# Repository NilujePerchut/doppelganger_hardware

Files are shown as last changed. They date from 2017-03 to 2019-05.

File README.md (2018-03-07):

# Doppelganger RevA0
_Niluje (c) 2018_

Joystick interface to Brook PCB and old video game systems.
This is the hardware part of the project,

The project is divided in three parts:
* The main board
* Arcade Adapter: an interface to arcade superguns for the doppelganger
* A BROOK fighting board replacement that allows to plug any USB device on the doppelganger main board

See in each project folder for more details.

## Firmware

See the software project.

## Acknowelegement

The idea is stolen from the MC Cthulu by Toodles.

## Licence

This hardware project is distribuated under the BSD 2-clauses licence.
SEE licence file for more information.

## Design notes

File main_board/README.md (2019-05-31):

# Doppelganger RevB0
_Niluje (c) 2018_

Joystick interface to Brook PCB and old video game systems.
This is the hardware part of the project,

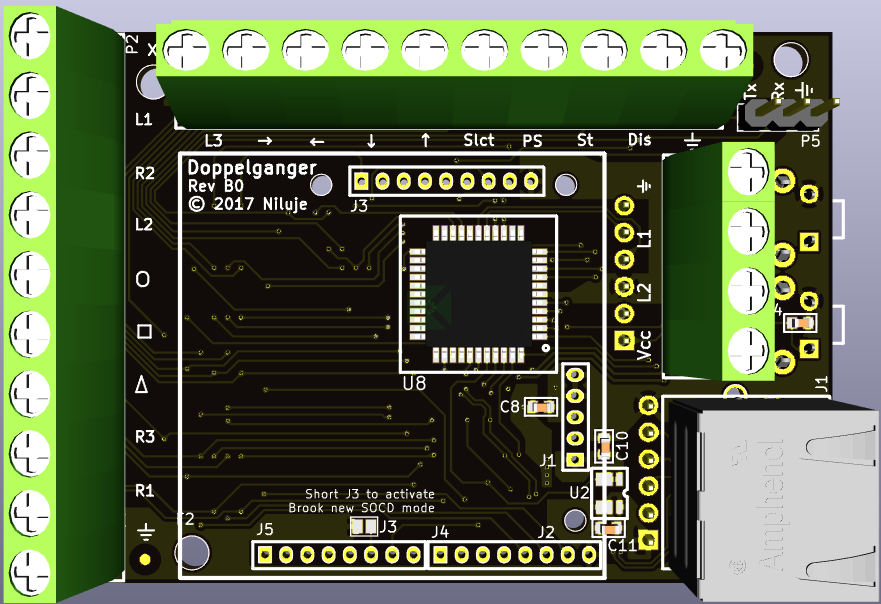
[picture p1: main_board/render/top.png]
Kicad render (top side)

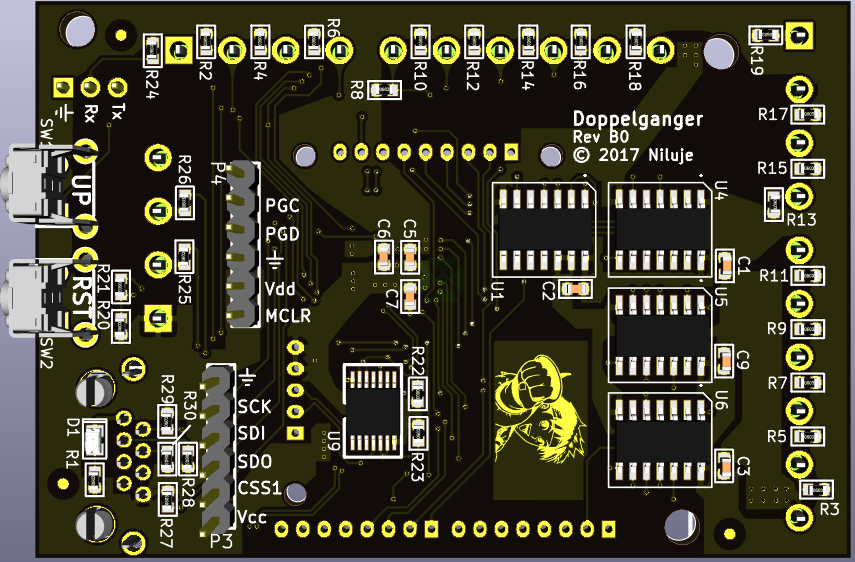
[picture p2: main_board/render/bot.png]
Kicad render (bottom side)


## RJ45 cabling

See the software project.

## Known bugs

Nothing for the moment

## Acknowelegement

The idea is stolen from the MC Cthulu by Toodles.

## Licence

This hardware project is distribuated under the BSD 2-clauses licence.
SEE licence file for more information.

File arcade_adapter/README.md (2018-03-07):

# Arcade Adapter RevB1
_Niluje (c) 2018_

Doppelganger addon board designated to support superguns, and (in the future) controllers with more than 8 wires. ie: Megadrive/Genesys.

This module is compatible with all Doppelganger versions (in case of RevA0, just apply all bug fixes listed in the Doppelganger README.md file).

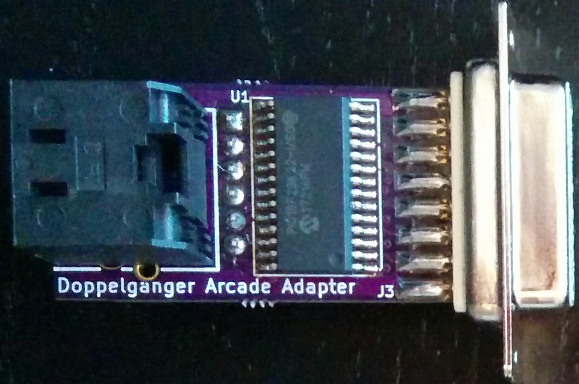
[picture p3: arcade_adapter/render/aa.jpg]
Arcade adapter first batch


## RJ45 cabling

Just use a straight Ethernet cable to connect the Arcade Adapter to the Doppelganger.

## SUBD15 cabling

### Supergun

The default SUBD15 for supergun is given below. But since all pins are connected to the
PIC microcontroller, it is possible to implement any required pinout by modifiing the C code.

Thus, it recommended to check the software for the currently supported pinouts.
For the moment, only one pinout supported is the SmallCab supergun.

| SUBD15 pin | function |
|---|---|
| 1 | Gnd |
| 2 | NC |
| 3 | MK |
| 4 | LK |
| 5 | MP |
| 6 | RIGHT |
| 7 | DOWN |
| 8 | Vcc |
| 9 | HK |
| 10 | COIN |
| 11 | START |
| 12 | HP |
| 13 | LP |
| 14 | LEFT |
| 15 | UP |

* NC does not mean "not connected" to the PIC microcontroller. It is just not connected to the supergun for this configuration.

## Firmware
This board must be used with the Doppelganger arcade adapter available in the Doppelganger software project.

## Known bugs

None for now (hopefuly)

## Licence

This hardware project is distribuated under the BSD 2-clauses licence.
SEE licence file for more information.

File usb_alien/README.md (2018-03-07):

# USB Alien RevA0
_Niluje (c) 2018_

This is an attempt to provide an _any_ USB interface to the Doppelganger board.
This board replaces the BROOK fighting board on the Doppelganger.
You can for example, mount the Doppelganger and the USB alien inside a TE2 and 
plug the TE2 USB to the USB Alien. This will allow the Doppelganger to access 
the TE2 USB.

## Status

Not tested yet.

## Licence

This hardware project is distribuated under the BSD 2-clauses licence.
SEE licence file for more information.

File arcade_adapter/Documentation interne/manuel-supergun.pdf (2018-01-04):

# SUPERGUN SMALLCAB

v1.6

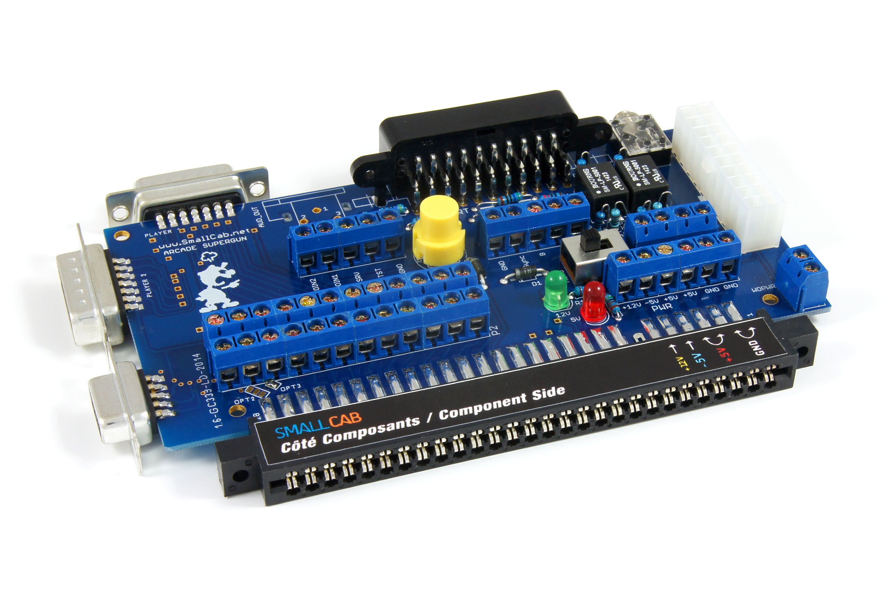
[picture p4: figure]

# MANUEL D'UTILISATION

### WWW.SMALLCAB.NET

# TABLE DES MATIÈRES

1. Présentation | page 3
2. Alimentation du Supergun | page 3
2.1. Alimentation ATX | page 3
2.2. Alimentation Arcade | page 3
2.3. Indicateur de voltage | page 3
3. Gestion du son | page 4
3.1. Switch Mono/Stéréo (SW1) | page 4
3.2. Prise casque (speakers) | page 4
3.3. Borniers audio droit et gauche (Right/Left) | page 4
3.4. Son sur la péritel | page 4
4. Schéma de la carte PCB du supergun | page 5
5. Contrôles | page 6
5.1. Connecteur DB15 | page 6
5.2. Connecteur DB9 | page 6
5.3. Borniers P1/P2 | page 7
5.4. Borniers OPT | page 7
6. Cablage JAMMA mono utilisé | page 8
7. Cablage JAMMA stéréo utilisé | page 9

WWW.SMALLCAB.NET - Page 2

# 1. PRÉSENTATION

Le Supergun SmallCab est une carte électronique qui permet d'utiliser une carte (PCB) JAMMA sur un téléviseur équipé d'une prise péritel. Il est compatible avec les cartes (PCB) JAMMA utilisant jusqu'à six boutons sur le conecteur JAMMA (Pandora Box par exemple). Vous pouvez utiliser un stick Neo Geo (port DB15) ou des joysticks et boutons d'arcade (bornier P1Bis et P2Bis).

Un switch permet de passer de mono à stéréo pour les PCB gérant la stéréo. Un bouton insert coin placer au centre du Supergun permet de passer les crédits directement à la carte (PCB) JAMMA.

La sortie péritel permet de diffuser l'image (seule la sortie RGB est supportée, pas la composite ni la S-Vidéo) ainsi que le son (seulement sur la version deluxe) sur votre téléviseur.

Afin d'éviter tout problème, veuillez éteindre le téléviseur avant de changer de carte (PCB) JAMMA.

# 2. ALIMENTATION DU SUPERGUN

# 2.1. Alimentation ATX

Vous pouvez utiliser une alimentation ATX de type Bronze Plus 80 à partie de 350W (connecteur 20 ou 24 points acceptés).

Les alimentation ATX présentent l'avantage d'être auto régulée et fonctionnent parfaitement avec de petites carte JAMMA comme les PandoraBox ou les Slot MVS (avec un seul port cartouche). Pour des cartes JAMMA plus importantes comme un slot MVS disposant de quatre ports ce type d'alimentation ne sera pas suffisante.

A noter que le -5V disponible dans les premières versions du standard ATX n'est actuellement plus disponible. L'absence de ce -5V peux entrainer un incompatibilité avec quelques très rare jeux.

# 2.2. Alimentation Arcade

Les alimentations Arcade ne sont pas auto régulés et nécessitent d'être réglée pour chaque jeu avec un voltmètre ce qui leur usage plus contraignant.

Pour connecter une alimentation Arcade sur nos Superguns il convient de relier :

- Le +5V de l'alimentation au bornier +5V du Supergun
- Le -5V de l'alimentation au bornier -5V du Supergun
- Le +12V de l'alimentation au bornier +12V du Supergun
- Le GND de l'alimentation au bornier GND du Supergun

# 2.3. Indicateur de voltage

La LED rouge indique la présence du 5V sur le Supergun.
Nb: Cette LED est une information de présence du +5V. Le Supergun peut être en survoltage ou en sous-voltage

La LED verte indique la présence du 12V sur le Supergun.

# 3. GESTION DU SON

# 3.1. Switch Mono/Stéréo (SW1)

Le Supergun dispose d'un switch Mono/Stéréo que vous devez positionner en fonction de la PCB que vou sutilisez. Ce switch doit être positionné sur Mono pour la plupart des cartes (PCB) JAMMA.
Le site Arcade Museum (http://www.arcade-museum.com/) référence un grand nombre de PCB et vous permettra de déterminer si votre PCB est de type mono ou stéréo.

Lorsque le switch (SW1) est positionné sur Mono, le signal audio est alors envoyé simultanément sur les hauts parleurs de droite et de gauche.

Pour les PCB disposant du mode stéréo sur le port JAMMA il convient de positionner le switch sur Stéréo. Les deux canaux seront alors répartit sur les hauts parleurs de droite et de gauche.

# 3.2. Prise casque (speakers)

La sortie casque permet de récupérer le son avec un casque ou des enceintes non amplifiés.
Dès que cette sortie est utilisée, le son est coupé et n'est plus disponible au niveau des borniers et de la prise péritel (version deluxe).

# 3.3. Borniers audio droit et gauche (Right/Left)

Le son disponible sur les borniers est amplifié et provient directement de votre PCB JAMMA.Le volume se règle directement sur votre PCB. Vous pouvez connecter des hauts parleurs 8Ohms directement sur les borniers R+,R- et L+,L-

# 3.4. Son sur la péritel

Sur la version Deluxe le son stéréo est disponible sur la prise péritel. Le son est atténué par deux transformateurs bourns afin de ne pas abimer l'amplificateur audio qui est intégré à votre téléviseur.

# 4. SCHÉMA DE LA CARTE PCB DU SUPERGUN

J2

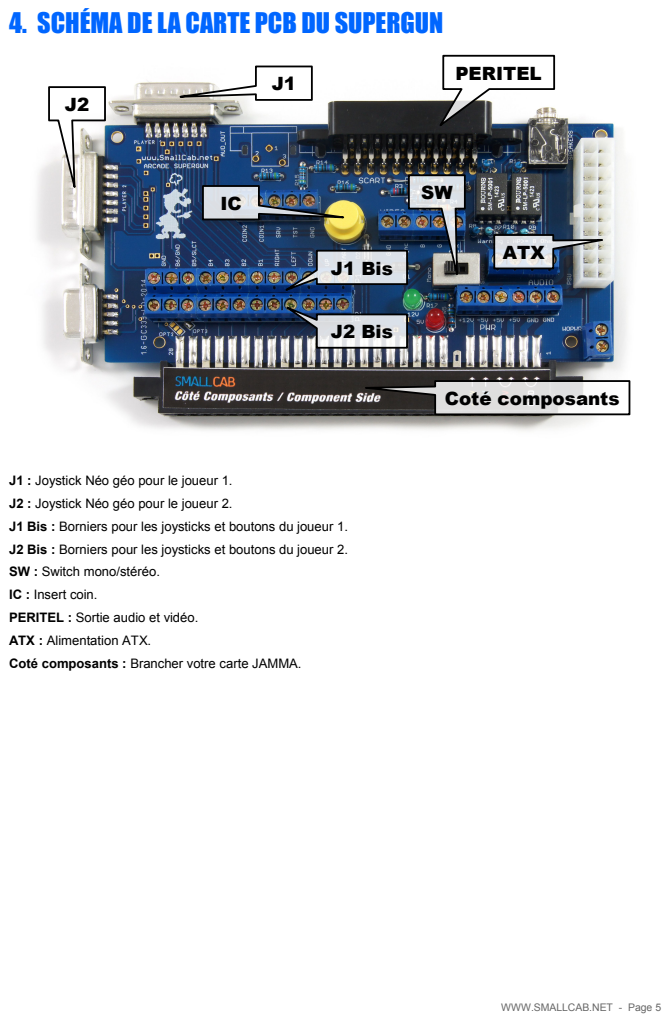
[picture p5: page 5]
J1 Bis; J2 Bis; PERITEL; ATX; Coté composants

J1 : Joystick Néo géo pour le joueur 1.
J2 : Joystick Néo géo pour le joueur 2.
J1 Bis : Borniers pour les joysticks et boutons du joueur 1.
J2 Bis : Borniers pour les joysticks et boutons du joueur 2.
SW : Switch mono/stéréo.
IC : Insert coin.
PERITEL : Sortie audio et vidéo.
ATX : Alimentation ATX.
Coté composants : Brancher votre carte JAMMA.

# 5. CONTRÔLES

# 5.1. Connecteur DB15

Le Supergun dispose de deux ports manette DB15 au standard Neo Geo.
Toutes les manettes Neo Geo sont donc compatible avec le Supergun
Cas des manettes "Cacahuète'. Pour fonctionner, ces manettes ont besoins d'être alimenté en +5V, celà est possible en soudant les pastilles P1_PWR (manette du joueur 1) et P2_PWR (manette du joueur 2).
Afin de répondre à toutes les attentes des joueurs, nouis avons fait évoluer le standard DB15 de la Neo Geo. Cela nous permet ainsi de gérer un 6ème bouton et d'intégrer un bouton "Insert Coin" bien pratique pour ajouter des crédits en pleine partie.

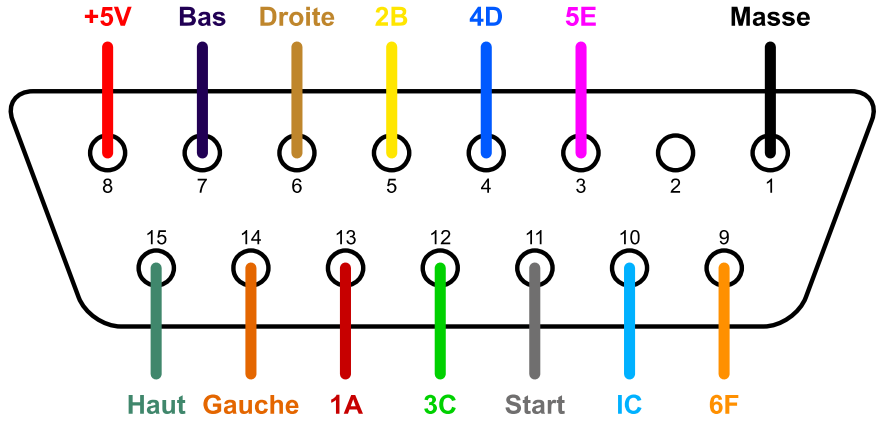
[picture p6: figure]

# 5.2. Connecteur DB9

Le port DB9 sert de Kick harness universel au Supergun SmallCab.
Le kick harness désigne un câblage "hors standard JAMMA" spécifique à certaine PCB comme les PCB CPS1/2 et 3.
Ce connecteur additionnel permet de câbler les boutons 5 et 6 (dans certains cas le bouton 4) non disponible dans le standard JAMMA.
Les Kick harness CPS 1/2 et 3 sont disponibles en option.

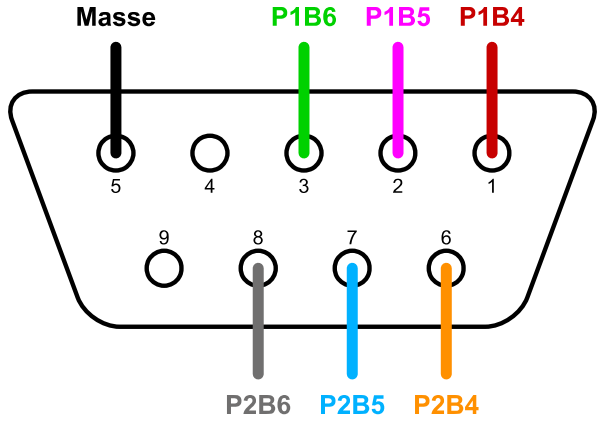
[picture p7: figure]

# 5.3. Borniers P1/P2

Ces borniers permettent de câbler directement le joystick et les 6 boutons du joueur 1 (borniers P1) ainsi que le joystick et les boutons du joueur 2 (borniers P2)

# 5.4. Borniers OPT

Les borniers optionnels permettent de connecter les boutons suivants:

- Test (TST) pour les PCB qui le gère, ajout d'un crédit au jeu sans incrémenter le compteur de crédit.
- Service (SRV) Permet de rentrer dans le paramétrage de la carte pour les PCB qui le gère.
- Insert coin 1 (COIN1) Ajout d'un crédit au jeu (plus incrémentation du compteur de crédit)
- Insert coin 2 (COIN2) Ajout d'un crédit au joueur 2 (plus incrémentation du compteur de crédit). Très peu de carte gère deux monnayeurs pour une PCB.

# 6. CABLAGE JAMMA MONO UTILISÉ

COTÉ COMPOSANT | COTÉ SOUDURE
GND (Masse) | 1 | A | GND (Masse)
GND (Masse) | 2 | B | GND (Masse)
+5V | 3 | C | +5V
+5V | 4 | D | +5V
- 5V | 5 | E | - 5V
+12V | 6 | F | +12V
| 7 H
Non utilisé | 8 | J | Non utilisé
Non utilisé | 9 | K | Non utilisé
Haut parleur + | 10 | L | Haut parleur -
Non utilisé | 11 | M | Setup -TST (Paramétrage)
Vidéo - Rouge | 12 | N | Vidéo - Vert
Vidéo - Bleu | 13 | P | Vidéo - Synchro
Vidéo - GND (Masse) | 14 | R | Service (Srv)
Setup -TST (Paramétrage) | 15 | S | Non utilisé
Coin J1 (Crédit) | 16 | T | Coin J2 (Crédit)/Test NeoGeo 64
J1 - Start | 17 | U | J2 - Start
J1 - Haut | 18 | V | J2 - Haut
J1 - Bas | 19 | W | J2 - Bas
J1 - Gauche | 20 | X | J2 - Gauche
J1 - Droite | 21 | Y | J2 - Droite
J1 - Bouton 1 | 22 | Z | J2 - Bouton 1
J1 - Bouton 2 | 23 | a | J2 - Bouton 2
J1 - Bouton 3 | 24 | b | J2 - Bouton 3
J1 - Bouton 4 | 25 | c | J2 - Bouton 4
J1 - Bouton 5 | 26 | d | J2 - Bouton 5
J1 - Bouton 6 (bornier) | 27 | e | J2 - Bouton 6 (bornier)
GND (Masse) | 28 | f | GND (Masse)

# 7. CABLAGE JAMMA STÉRÉO UTILISÉ

COTÉ COMPOSANT | COTÉ SOUDURE
GND (Masse) | 1 | A | GND (Masse)
GND (Masse) | 2 | B | GND (Masse)
+5V | 3 | C | +5V
+5V | 4 | D | +5V
- 5V | 5 | E | - 5V
+12V | 6 | F | +12V
| 7 H
Non utilisé | 8 | J | Non utilisé
Non utilisé | 9 | K | Non utilisé
Haut parleur R (droit) | 10 | L | Haut parleur L (gauche)
Non utilisé | 11 | M | Setup -TST (Paramétrage)
Vidéo - Rouge | 12 | N | Vidéo - Vert
Vidéo - Bleu | 13 | P | Vidéo - Synchro
Vidéo - GND (Masse) | 14 | R | Service (Srv)
Setup -TST (Paramétrage) | 15 | S | Non utilisé
Coin J1 (Crédit) | 16 | T | Coin J2 (Crédit)/Test NeoGeo 64
J1 - Start | 17 | U | J2 - Start
J1 - Haut | 18 | V | J2 - Haut
J1 - Bas | 19 | W | J2 - Bas
J1 - Gauche | 20 | X | J2 - Gauche
J1 - Droite | 21 | Y | J2 - Droite
J1 - Bouton 1 | 22 | Z | J2 - Bouton 1
J1 - Bouton 2 | 23 | a | J2 - Bouton 2
J1 - Bouton 3 | 24 | b | J2 - Bouton 3
J1 - Bouton 4 | 25 | c | J2 - Bouton 4
J1 - Bouton 5 | 26 | d | J2 - Bouton 5
J1 - Bouton 6 (bornier) | 27 | e | J2 - Bouton 6 (bornier)
GND (Masse) | 28 | f | GND (Masse)

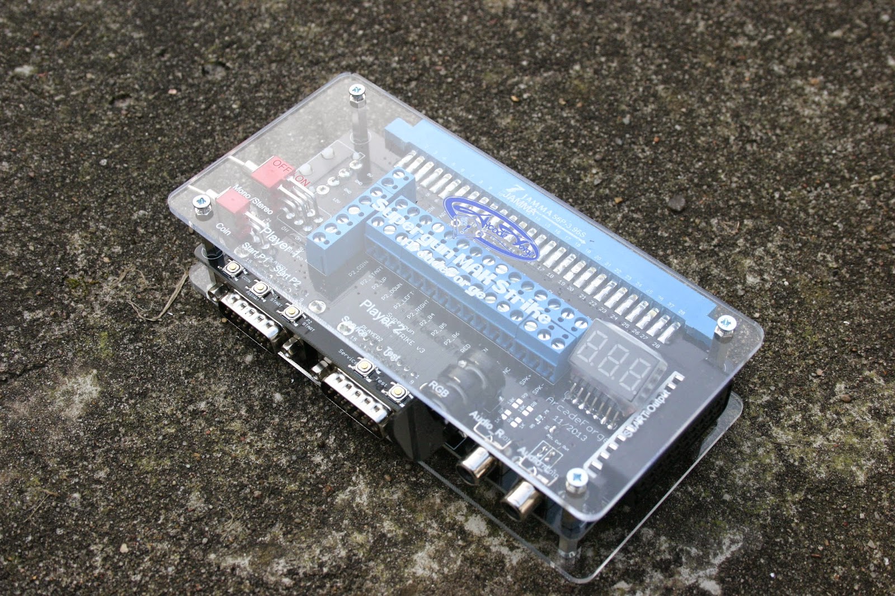
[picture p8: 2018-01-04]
arcade_adapter/Documentation interne/Supergun MAK Strike - ArcadeForge_fichiers/MAK_002.JPG

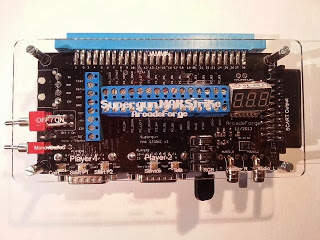
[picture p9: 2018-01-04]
arcade_adapter/Documentation interne/Supergun MAK Strike - ArcadeForge_fichiers/MAK_Strike_v3_04.jpg

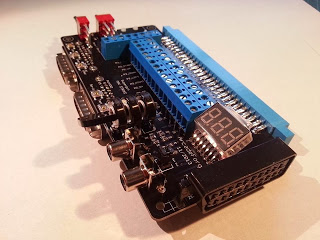
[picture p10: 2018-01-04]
arcade_adapter/Documentation interne/Supergun MAK Strike - ArcadeForge_fichiers/MAK_Strike_v3_00.jpg

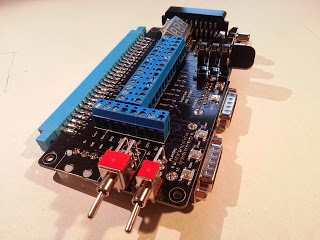
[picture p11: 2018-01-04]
arcade_adapter/Documentation interne/Supergun MAK Strike - ArcadeForge_fichiers/MAK_Strike_v3_01.jpg

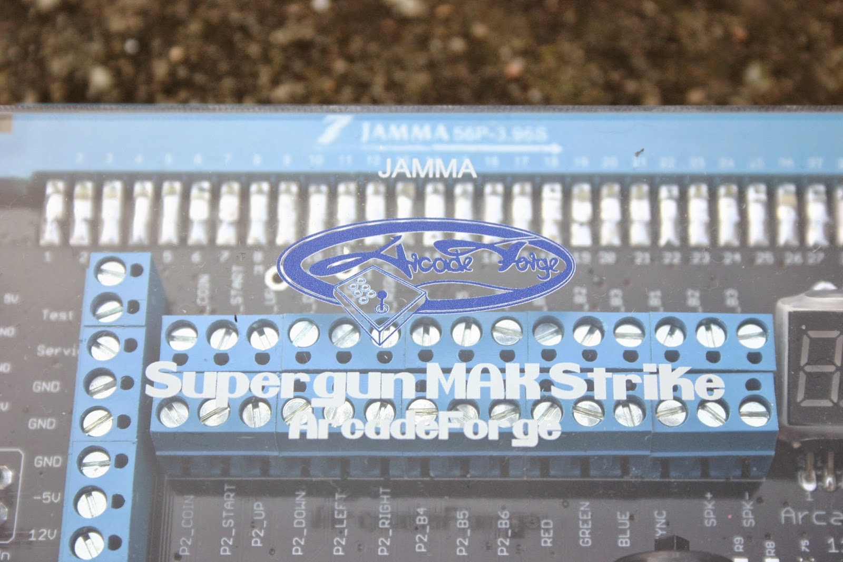
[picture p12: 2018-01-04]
arcade_adapter/Documentation interne/Supergun MAK Strike - ArcadeForge_fichiers/_MAK_009.JPG

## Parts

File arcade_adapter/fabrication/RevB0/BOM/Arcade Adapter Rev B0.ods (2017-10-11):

Arcade adapter Rev B0
Designator | Quantity | Manufacturer | Reference | SMD pins | TH pins | Total SMD | Total TH | Package | Element 14
C3,C2,C1 | 3 | Any | 100nF 10V X7R | 2 | 0 | 6 | 0 | SMD 0603 | 2522597
R4,R2 | 2 | Any | 330R 5 % | 2 | 0 | 4 | 0 | SMD 0603 | 2447339
R3 | 1 | Any | 100R 5 % | 2 | 0 | 2 | 0 | SMD 0603 | 2447227
R1 | 1 | Any | 10K 5 % | 2 | 0 | 2 | 0 | SMD 0603 | 2074170
D2,D1 | 2 | Dialight | LED verte 5988170107F | 2 | 0 | 4 | 0 | SMD 0805 | 1465996
J3 | 1 | Multicomp | SUBD15 à souder | 15 | 0 | 15 | 0 | SMD DB15F_CI | 1084693
J1 | 1 | Amphénol | RJ45 | 0 | 8 | 0 | 8 | TH | 1849917
J2 | 1 | NA | 6 pins 2.54mm header | 0 | 6 | 0 | 6 | TH | NA
U1 | 1 | Microchip | PIC18F23K22-I/SO | 28 | 0 | 28 | 0 | SMD SOIC-28 | 2315850

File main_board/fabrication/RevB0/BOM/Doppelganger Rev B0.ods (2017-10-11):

Doppelganger Rev B0
Designator | Quantity | Manufacturer | Reference | SMD pins | TH pins | Total SMD | Total TH | Package | Element 14
C2,C3,C4,C5,C6,C8,C9,C1,C10 | 9 | Any | 100nF 10V X7R | 2 | 0 | 18 | 0 | SMD 0603 | 2522597
C7 | 1 | Any | 330nF 10V X7R | 2 | 0 | 2 | 0 | SMD 0603 | 2524838
C11 | 1 | Any | 4.7µF 10V X5R | 2 | 0 | 2 | 0 | SMD 0603 | 2320818
R9,R28,R24,R23,R22,R20,R19,R18,R17,R16,R15,R13,R12,R11,R10,R8,R7,R6,R5,R4,R3,R2,R14 | 23 | Any | 10K 5 % | 2 | 0 | 46 | 0 | SMD 0603 | 2074170
R29,R27 | 2 | Any | 3K5 1 % | 2 | 0 | 4 | 0 | SMD 0603 | 2447361
R26,R1,R25 | 3 | Any | 330R 5 % | 2 | 0 | 6 | 0 | SMD 0603 | 2447339
R21 | 1 | Any | 100R 5 % | 2 | 0 | 2 | 0 | SMD 0603 | 2447227
R30 | 1 | Any | 4K7 5 % | 2 | 0 | 2 | 0 | SMD 0603 | 2694880
P6 | 1 | Any | Bornier 5mm pitch 4 pins | 0 | 4 | 0 | 4 | BORNIER4 | 3089058
P2,P1 | 2 | Any | Boernier 5mm pitch 10 pins | 0 | 10 | 0 | 20 | BORNIER_10 | 1793681
SW2,SW1 | 2 | NA | Push button | 0 | 4 | 0 | 8 | TH | NA
P5 | 1 | NA | 3 pins 2.54mm header | 0 | 3 | 0 | 3 | TH | NA
U1 | 1 | Texas instruments | 74HC32M96 | 14 | 0 | 14 | 0 | SMD SOIC-14 | 2458515
U4,U5,U6 | 3 | Texas Instruments | 74LVC07ADR | 14 | 0 | 42 | 0 | SMD SOIC-14 | 9592660
U8 | 1 | Microchip | 18F45K50-I/PT | 44 | 0 | 44 | 0 | SMD TQFP44 | 2305837
U9 | 1 | Nxperia | 74HC4066D-Q100,118 | 14 | 0 | 14 | 0 | SMD TSSOP14 | 2445241
J1 | 1 | Amphenol | RJ45 | 0 | 10 | 0 | 10 | TH | 1849917
P3,P4 | 2 | NA | 6 pins 2.54mm header | 0 | 6 | 0 | 12 | TH | NA
D1 | 1 | Dialight | LED verte 5988170107F | 2 | 0 | 2 | 0 | SMD 0805 | 1465996
J2 | 1 | NA | 2mm headers | 0 |  | 0 | 0 | TH | NA
U2 | 1 | Vishay | SIP32510DT-T1-GE3 | 6 | 0 | 6 | 0 | SMD TSOT-23-6 | 2361514
 |  | Total
Total SMD pins | 204
Total TH pins | 57

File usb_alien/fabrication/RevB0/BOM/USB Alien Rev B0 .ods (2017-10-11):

USB Alien RevB0
Designator | Quantity | Manufacturer | Reference | SMD pins | TH pins | Total SMD | Total TH | Package | Element 14 | Designation | Supplier and ref
P2,P1 | 2 | Multicomp | 4 pin 3.81mm connector | 0 | 4 | 0 | 8 | TH | 2007987
C2,C1 | 2 | Any | 100nF 10V X7R | 2 | 0 | 4 | 0 | SMD 0603 | 2522597
U2,U1 | 2 | Texas Instruments | 4 NAND2 gate | 14 | 0 | 28 | 0 | SMD SOIC-14 | 9590870
J2 | 1 | NA | 2.54 mm pitch 2x12 header | 0 | 24 | 0 | 24 | HE-10_2x12_2.54 | NA
P4,P3 | 2 | Multicomp | 10 pin 3.81mm connector | 0 | 10 | 0 | 20 | TH | 2007993 | BORNIER_10
D1 | 1 | Dialight | LED verte 5988170107F | 2 | 0 | 2 | 0 | SMD 0805 | 1465996
J1 | 1 | NA | Brook adapter | 0 | 30 | 0 | 30 | TH | NA
R1 | 1 | Any | 330R 5 % | 2 | 0 | 2 | 0 | SMD 0603 | 2447339

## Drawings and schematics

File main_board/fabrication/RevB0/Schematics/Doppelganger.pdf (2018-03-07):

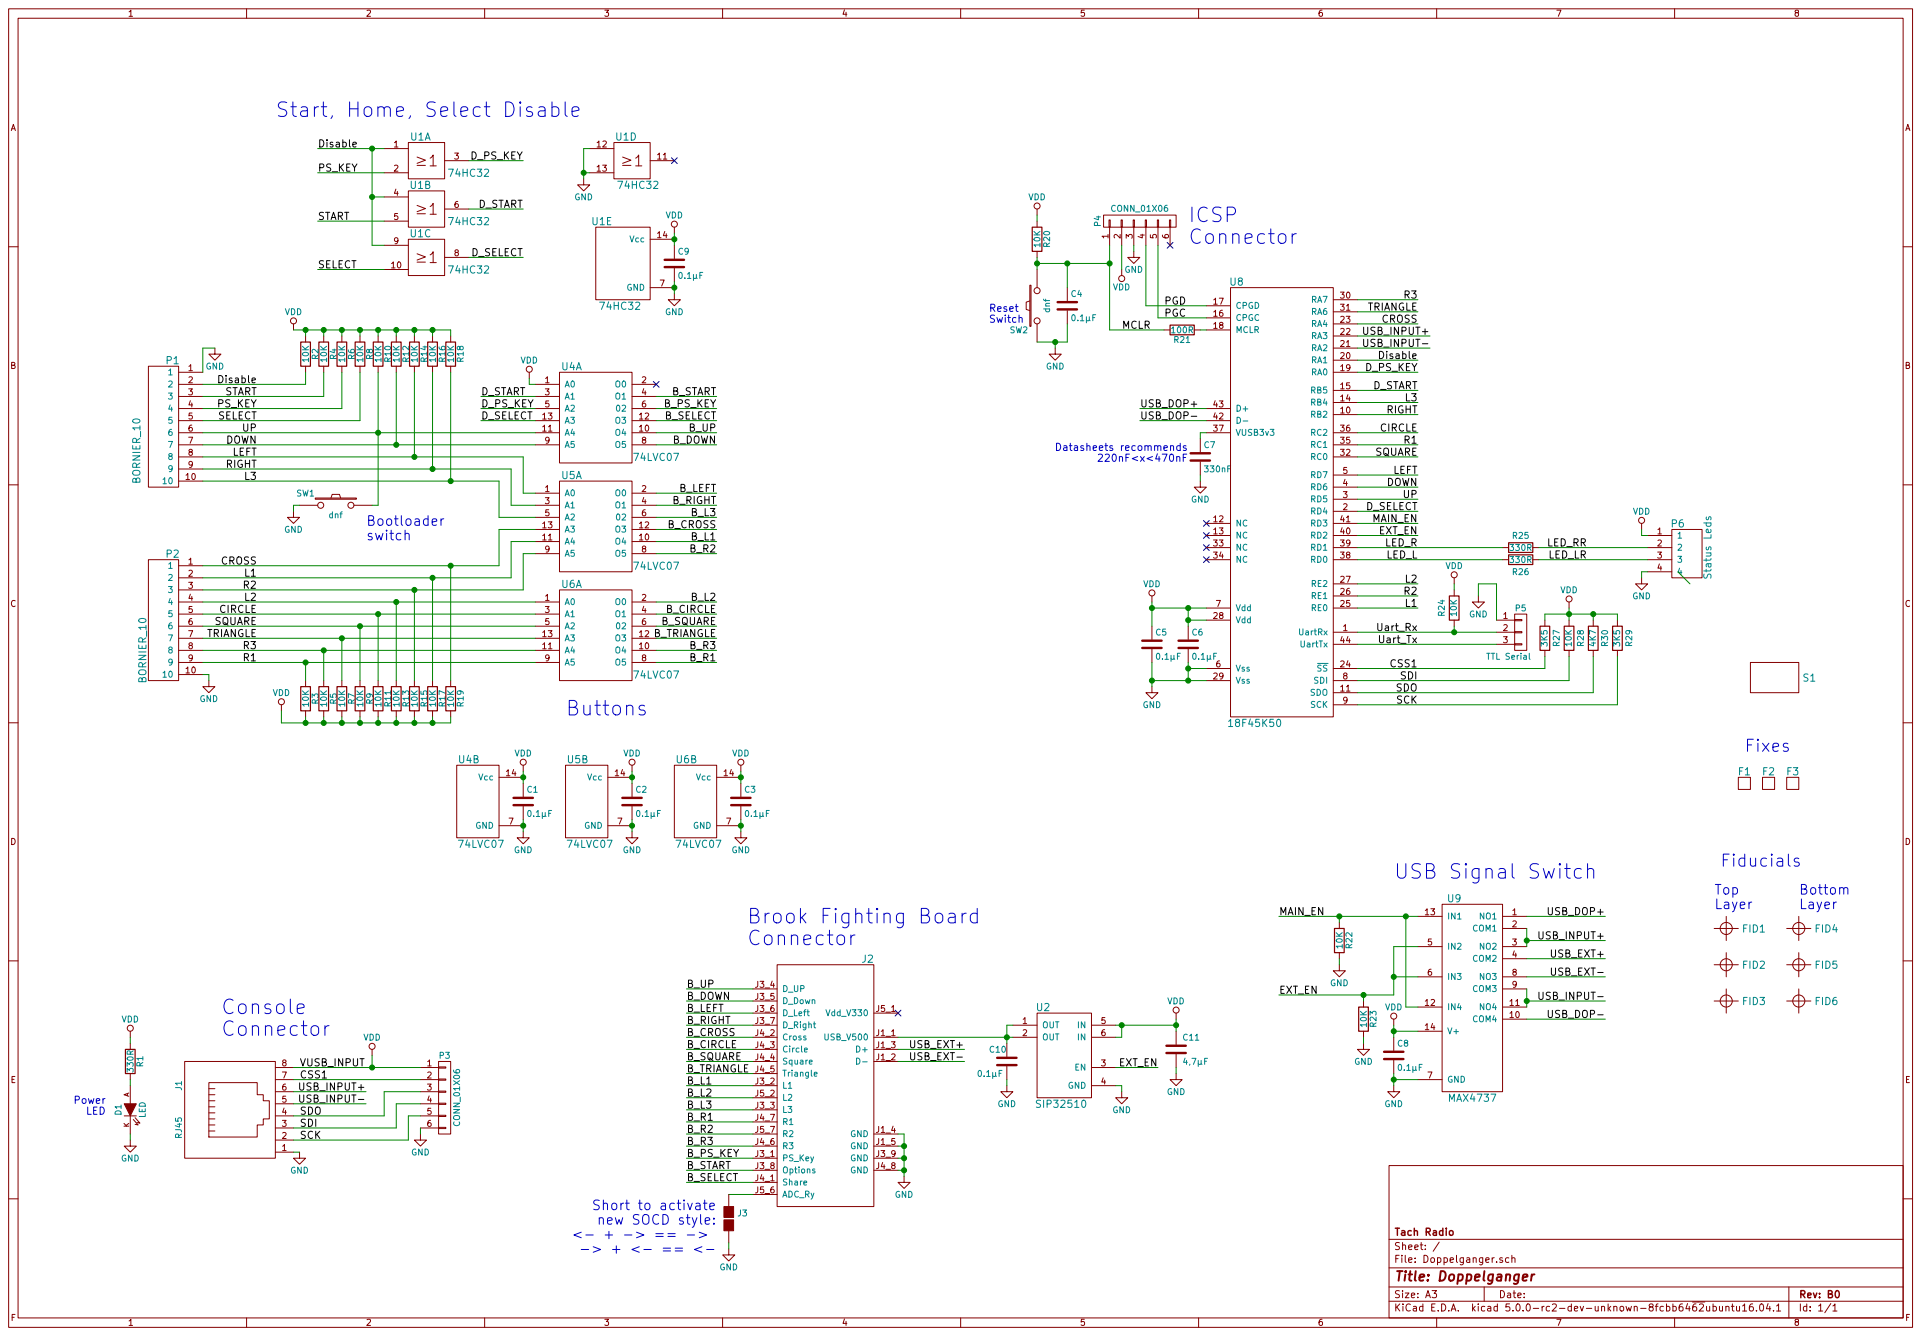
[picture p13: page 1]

Start, Home, Select Disable

LED_L | LED_LR | 3

4 | 02 O4 O3 O0 O1 | 8 A5 9 U6A 10 A4 11 12 A3 13 2 A1 3 4 A2 5

CIRCLE 5 | | | A0 1 | 6 O5 B_CIRCLE

6 | | | | B_SQUARE
7 | | | | | | B_TRIANGLE
8 | | | | | B_R3

J3 GND Short to activate

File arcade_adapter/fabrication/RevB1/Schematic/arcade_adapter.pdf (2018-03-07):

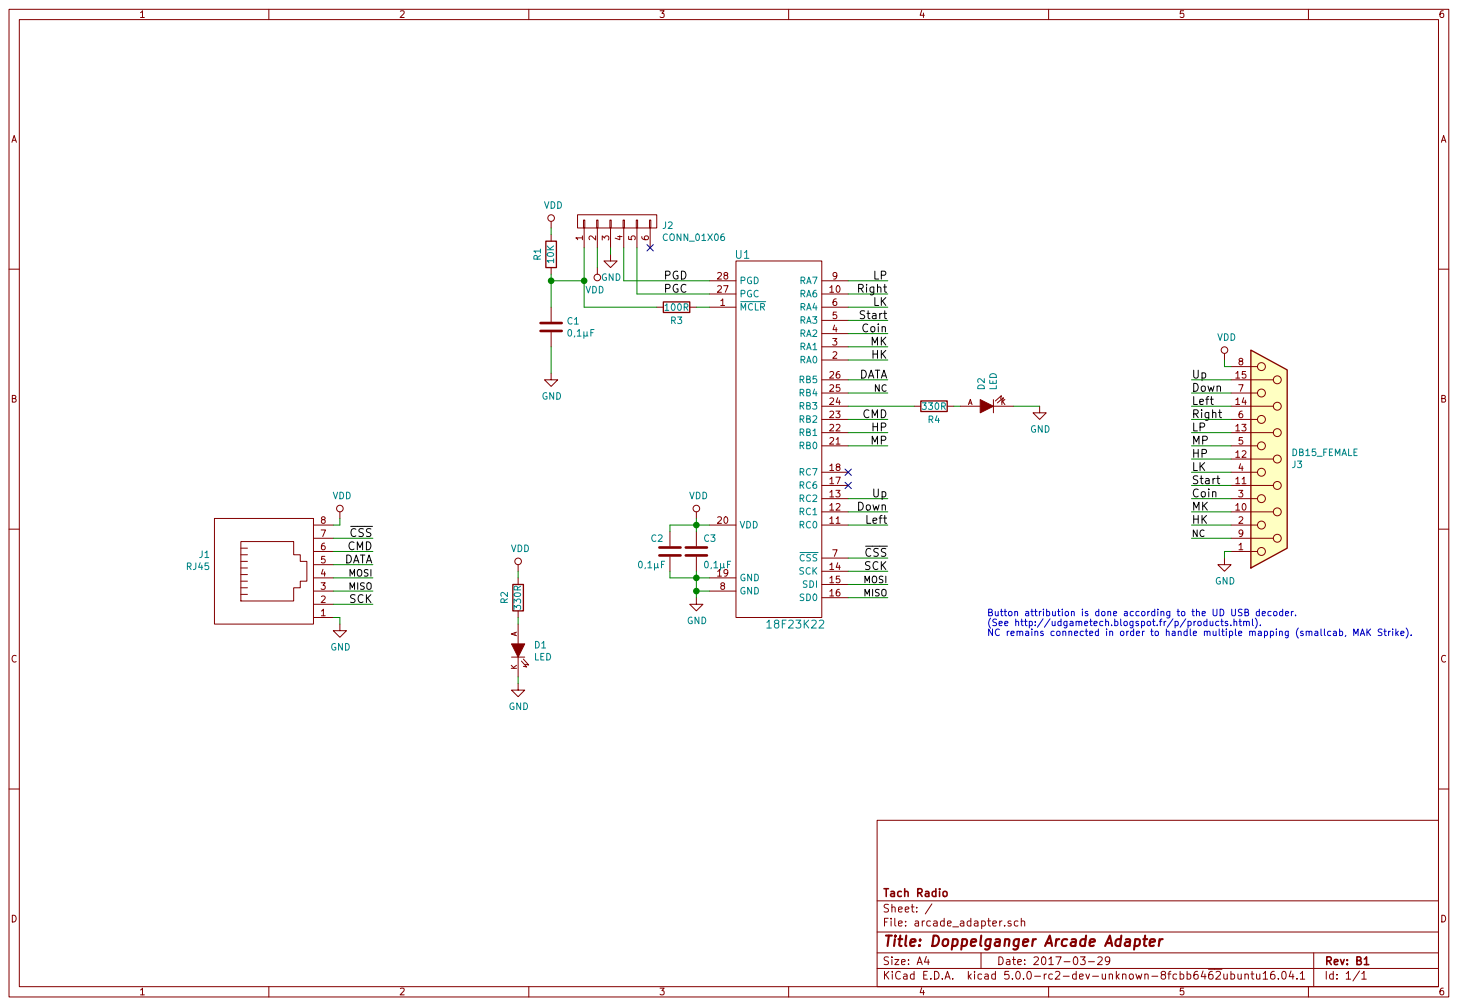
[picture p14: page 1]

LP Right Left DownUp
LKMP
Start MK
Coin

Button attribution is done according to the UD USB decoder.
(See http://udgametech.blogspot.fr/p/products.html).
NC remains connected in order to handle multiple mapping (smallcab, MAK Strike).

Id: 1/1 Title: Doppelganger Arcade Adapter

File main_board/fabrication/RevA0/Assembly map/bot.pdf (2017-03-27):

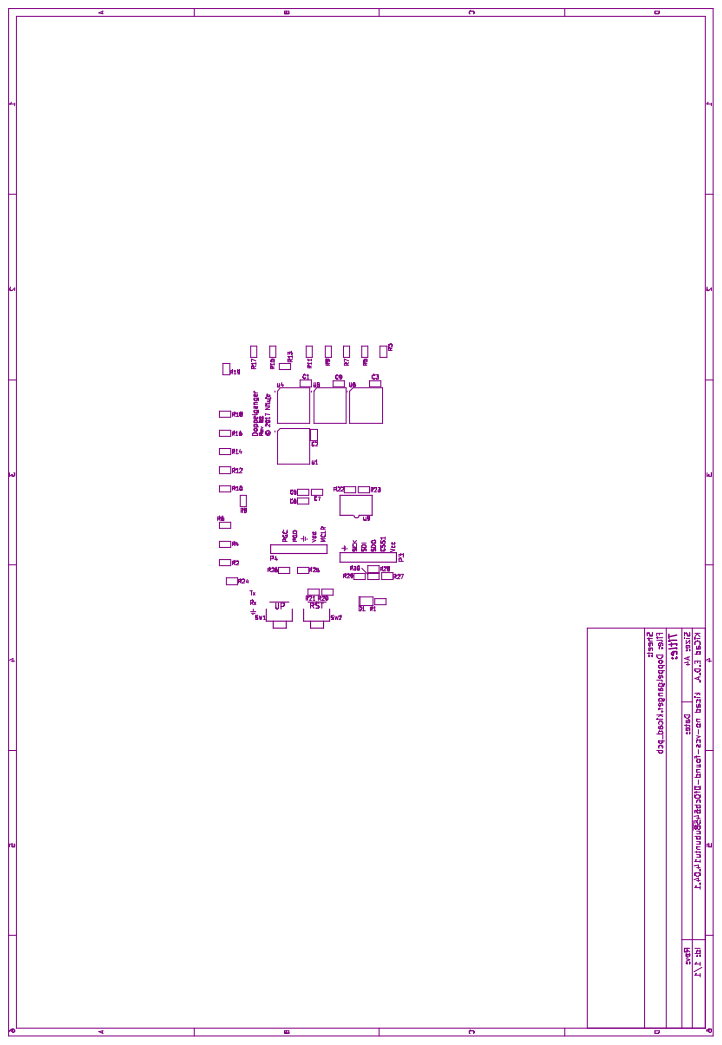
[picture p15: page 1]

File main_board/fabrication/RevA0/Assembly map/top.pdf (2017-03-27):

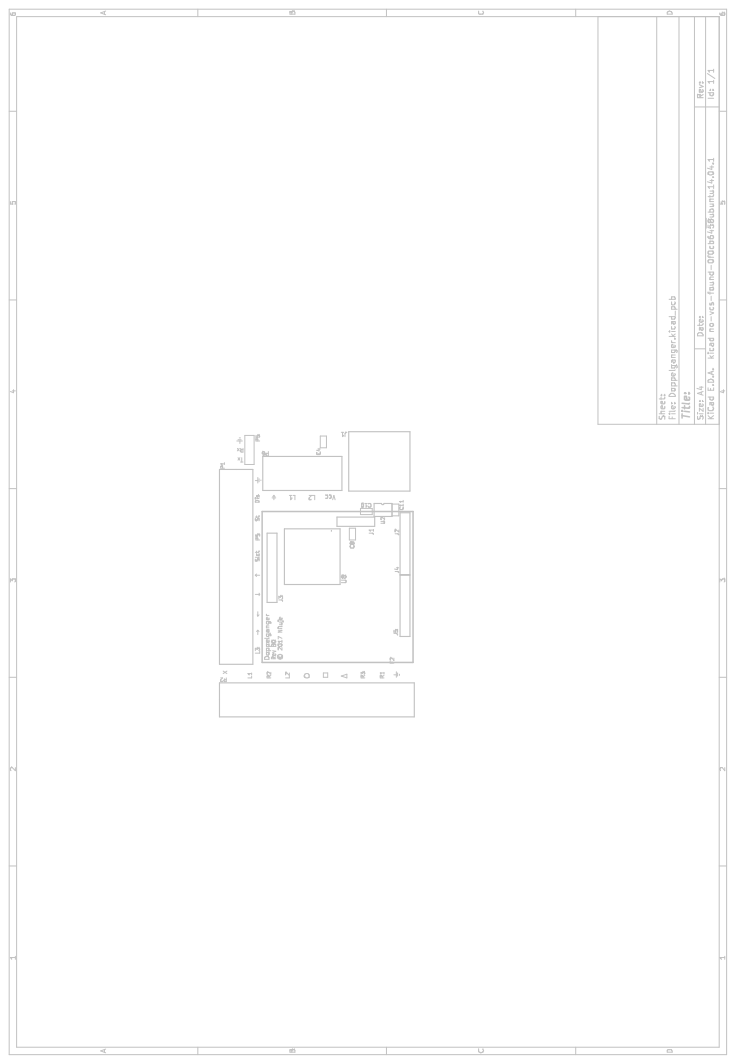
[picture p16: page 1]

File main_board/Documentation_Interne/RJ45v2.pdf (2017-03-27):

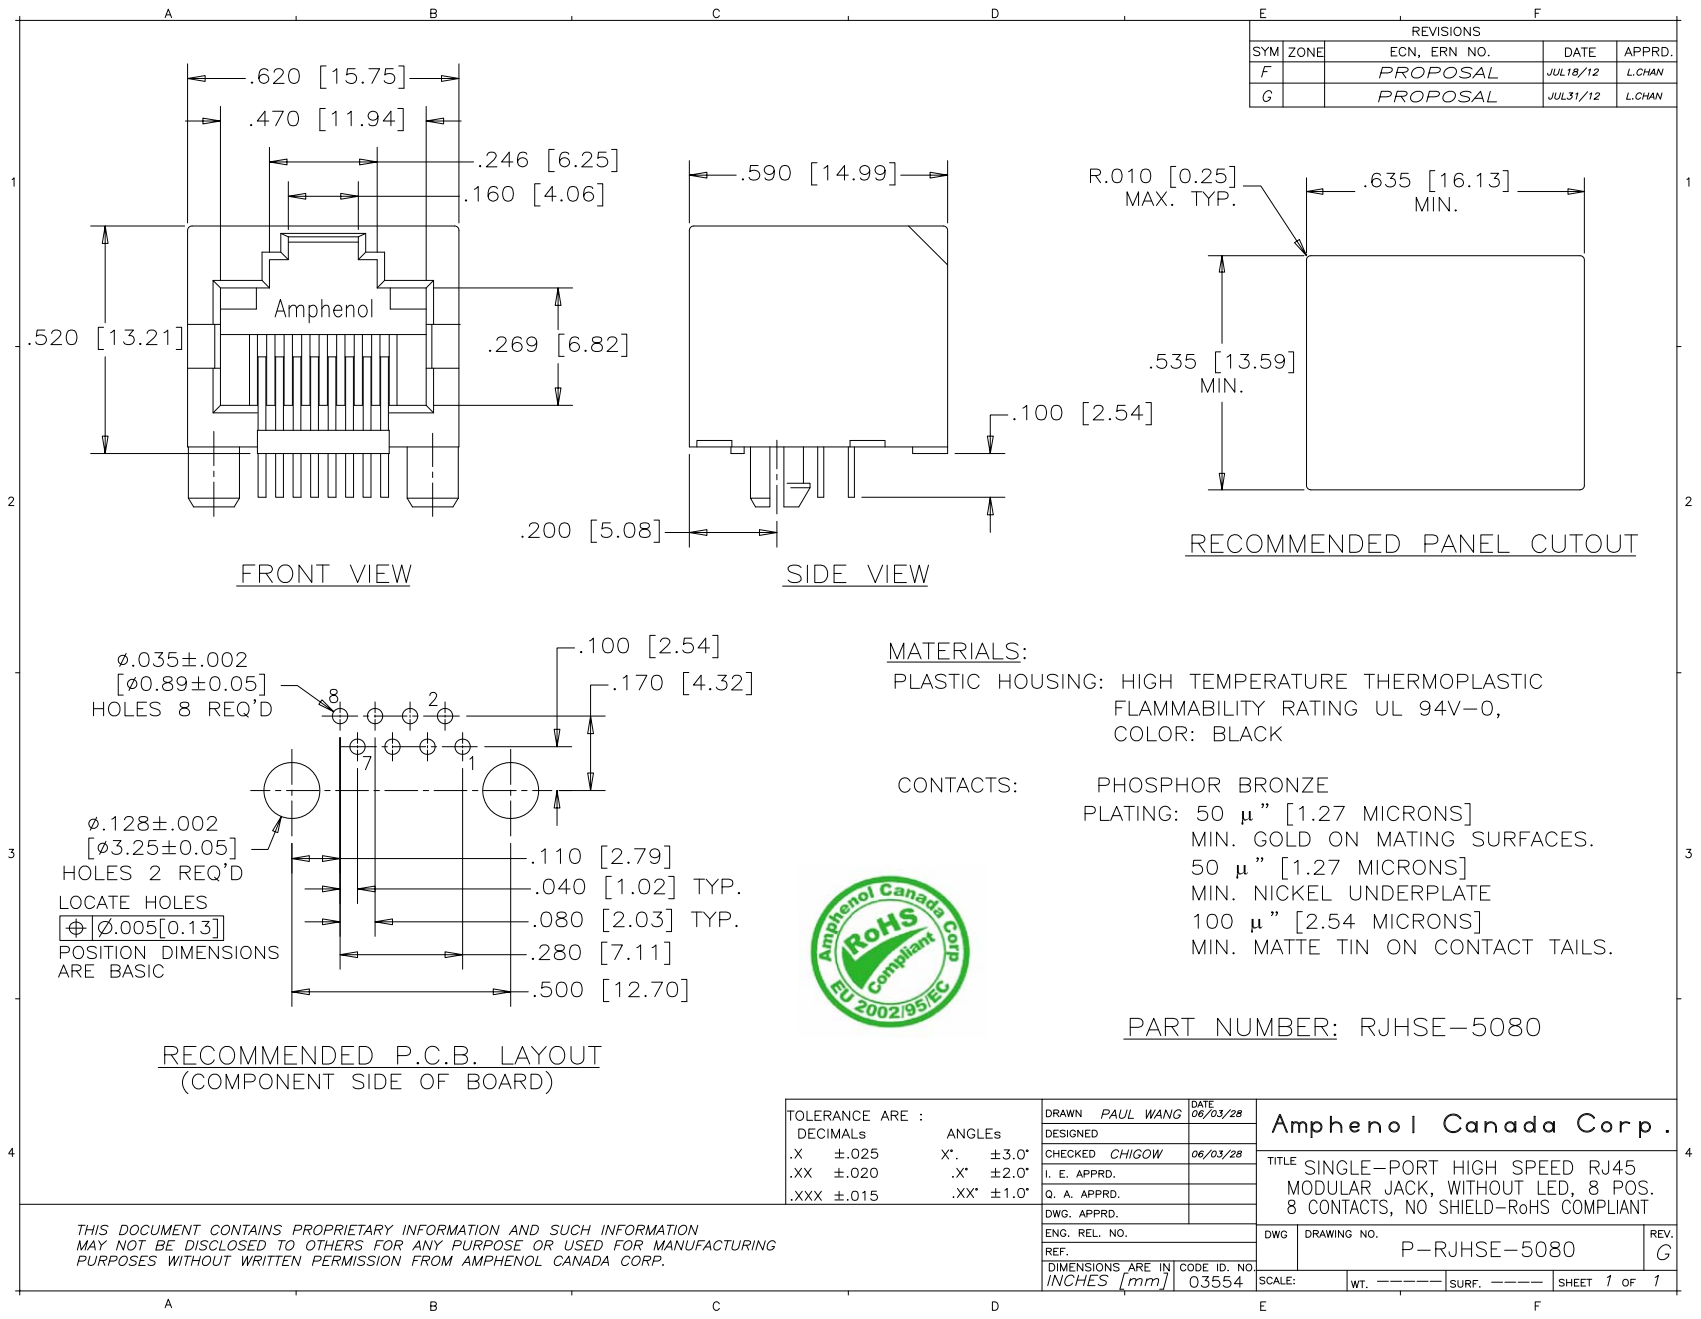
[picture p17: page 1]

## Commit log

2017-03-27 Split project into 3 projects
    [CPU.sch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]
2017-10-03 Pre teardrops
    [CPU.sch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]
2017-10-07 Updates kicad scripts (teardrop action plugin)
2018-01-01 Last changes
    [Doppelganger.kicad_pcb, Doppelganger.sch]
2018-01-04 Arcade adapter RevB1 first commit
    [arcade_adapter.kicad_pcb, arcade_adapter.sch]
2018-03-07 Arcade adapter revb1 fabrication update
    [arcade_adapter-B.Cu.gbl, arcade_adapter-B.Fab.gbr, arcade_adapter-B.Mask.gbs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]
2018-03-07 Update main board schematics and creates readme for usb alien
2018-03-07 Fix images in main board readme
2019-05-31 Fix Wrong revision in main board readme
